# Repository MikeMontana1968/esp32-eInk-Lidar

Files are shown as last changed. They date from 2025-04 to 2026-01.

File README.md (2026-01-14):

# ESP32 eInk+LiDAR Motorcycle Fuel Gauge

An ESP32-based fuel tank monitoring system using a LIDAR sensor and e-ink display. Designed for vehicle fuel level monitoring with real-time display of fuel percentage, remaining gallons, estimated range, and historical consumption data.

The lidar (a vlx sensor from ada-fruit) sensor has a neobydium magnet epoxied to it so that it sticks to the upper-inside of the fuel tank and points down. The code reads the time-of-flight to the level of gasoline remaining in the tank about every 1s, with 10 reads spaced 10ms apart and weighted with std-dev to filter out vibrations, and sloshing effects of the surface. Orignially an ultra-sonic transducer was used but the gasoline destroyed the sensor. The overall accuracy is "good enough" to know when to get gas "soon". Some of my other repos explore other ways to estimate fuel consumption/range for the motorcycle.

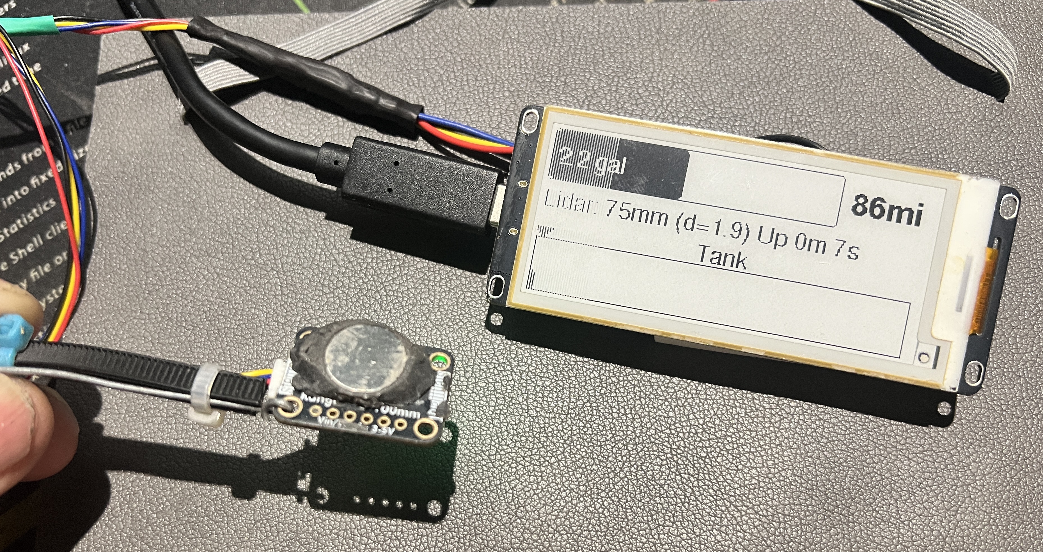
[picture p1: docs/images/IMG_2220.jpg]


Here's the 3d scan of the fuel tank. As you can see it's curved in three dimensions - the width curves out, then inward. As does the height along the horizontal axis. The curves are complex enough that a 5th order polynomial is needed to estimate fuel capacity for a given point on the z-axis. ClaudeAI was used to generate the polynomial <b>by working from the 3d scan of the tank</b> directly! Very impressive. The STL itself is available in .\stl\

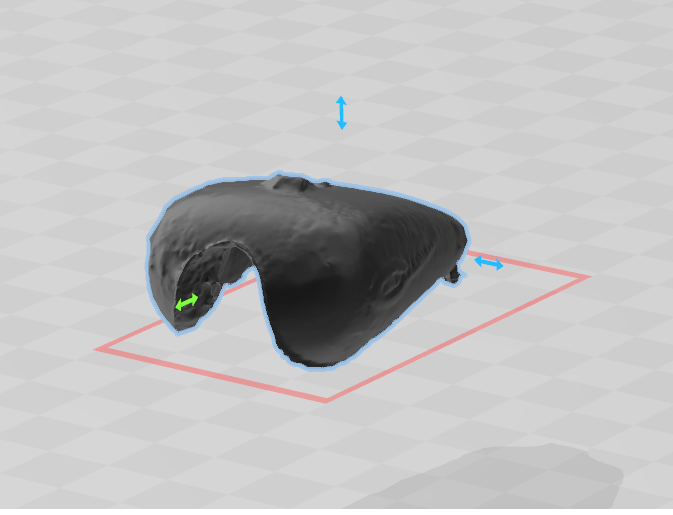
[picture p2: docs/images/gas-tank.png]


## Project Structure

```
heltec-gas-gauge/
├── platformio.ini              # PlatformIO build configuration
├── src/
│   ├── main.cpp                # Main entry point
│   ├── classes/
│   │   ├── EinkDisplayTask.cpp     # E-ink display task
│   │   ├── MyTask.cpp          # FreeRTOS task base class
│   │   ├── TankCapacity.cpp    # Fuel volume calculations
│   │   └── VlxTask.cpp         # LIDAR sensor task (VL6180X)
│   └── README.md               # This file
└── stl/                        # 3D printable enclosure files
```

## Hardware Requirements

### Microcontroller
- **Heltec Vision Master E290** (ESP32-S3 based board with integrated e-ink display)
- 296x128 pixel e-ink display

### Sensor
- **Adafruit VL6180X** Time-of-Flight LIDAR sensor
- Range: 0-255mm
- Mounted above fuel tank to measure fuel level depth

### Pin Configuration
| Function | GPIO Pin |
|---|---|
| I2C SDA  | GPIO 39  |
| I2C SCL  | GPIO 38  |
| VEXT Power | GPIO 18 |

### Tank Configuration Defaults
| Parameter | Default Value |
|---|---|
| Full tank distance | 10mm |
| Empty tank distance | 152mm |
| Tank capacity | 4.5 gallons |
| Average MPG | 40 |
| Screen refresh interval | 10 seconds |

## Build Process (PlatformIO)

### Prerequisites
- [VS Code](https://code.visualstudio.com/) with [PlatformIO extension](https://platformio.org/install/ide?install=vscode)

### platformio.ini
```ini
[env:vision-master-e290]
platform = espressif32
board = heltec_wifi_lora_32_V3
framework = arduino
monitor_speed = 115200
monitor_filters = esp32_exception_decoder
board_upload.use_1200bps_touch = true
build_flags =
  -D ARDUINO_USB_CDC_ON_BOOT=1
  -D Vision_Master_E290
  -D CORE_DEBUG_LEVEL=4
```

### Log Levels (CORE_DEBUG_LEVEL)
| Value | Level | Shows |
|---|---|---|
| 0 | None | Nothing |
| 1 | Error | `ESP_LOGE` only |
| 2 | Warn | `ESP_LOGE`, `ESP_LOGW` |
| 3 | Info | `ESP_LOGE`, `ESP_LOGW`, `ESP_LOGI` |
| 4 | Debug | All above + `ESP_LOGD` |
| 5 | Verbose | Everything including `ESP_LOGV` |

### Build and Upload
```powershell
pio run --target upload
```

### Monitor Serial Output
```powershell
pio device monitor
```

## Architecture

The system uses FreeRTOS to run two independent tasks:

| Task | Stack Size | Priority | Function |
|---|---|---|---|
| VlxTask | 8192 bytes | 3 | Continuously samples LIDAR sensor (~20 samples/cycle) |
| EinkDisplayTask | 16384 bytes | 3 | Updates e-ink display periodically |

### Source Files

| File | Description |
|---|---|
| `main.cpp` | Main entry point, initializes tasks |
| `classes/VlxTask.cpp` | LIDAR sensor driver, calculates mean/stddev, maintains history buffer |
| `classes/EinkDisplayTask.cpp` | Renders fuel gauge, stats, and historical graph on e-ink |
| `classes/TankCapacity.cpp` | Converts distance readings to volume using tank geometry |
| `classes/MyTask.cpp` | FreeRTOS task wrapper base class |

### Data Flow
1. VlxTask reads 20 samples from VL6180X sensor per cycle
2. Calculates average distance and standard deviation
3. Stores result in 200-element ring buffer for history
4. EinkDisplayTask retrieves latest data via mutex-protected access
5. TankCapacity converts distance to volume (gallons/liters)
6. Display renders fuel gauge, statistics, and historical bar graph

## Display Features

- Current fuel level percentage with bar graph
- Remaining fuel volume (gallons)
- Estimated driving range (miles)
- 200-sample historical fuel level graph
- Sensor uptime and status
- Error messages for sensor failures

## Customization

Tank parameters can be set when creating the EinkDisplayTask:

```cpp
einkTask = new EinkDisplayTask(
    I2C_SDA, I2C_SCL,   // I2C pins
    vlxTask,            // Pointer to VlxTask
    10,                 // mmFullTank - distance when full
    152,                // mmEmptyTank - distance when empty
    4.5,                // galCapacity - tank capacity in gallons
    40,                 // mpgAvg - average fuel economy
    10                  // secRefresh - display refresh interval
);
```

## 3D Printed Enclosure

STL files for a custom enclosure are included in the `/stl/` directory:
- `E290 Bottom.stl` - Bottom housing
- `E290 Top.stl` - Top housing
- `E290 Buttons.stl` - Button interface

## Dependencies

Managed automatically by PlatformIO:
- `heltec-eink-modules` - Heltec e-ink display driver
- `Adafruit_VL6180X` - VL6180X LIDAR sensor driver
- `Adafruit_GFX` - Graphics library

## License

See LICENSE file for details.

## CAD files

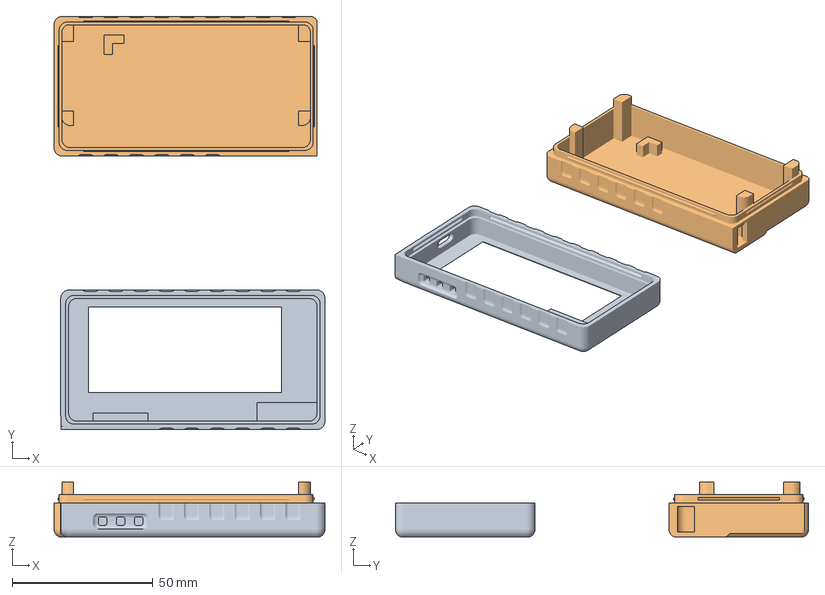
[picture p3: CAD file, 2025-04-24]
stl/E290 Top2.3mf
96.2 x 146.7 x 19.5 mm

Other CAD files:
stl/3dscan-of-fuel-tank.stl
stl/E290 Bottom.stl
stl/E290 Top.stl
stl/E290 Buttons.stl

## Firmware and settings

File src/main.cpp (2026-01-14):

/*
Set Board Type to: Vision Master E290
https://github.com/todd-herbert/heltec-eink-modules/blob/main/docs/WirelessPaper/wireless_paper.md

*/
#define LOG_LOCAL_LEVEL ESP_LOG_VERBOSE
#define I2C_SDA GPIO_NUM_39
#define I2C_SCL GPIO_NUM_38
#define TAG_MAIN "main"

#include "classes/VlxTask.cpp"
#include "classes/EinkDisplayTask.cpp"

VlxTask *vlxTask;
EinkDisplayTask *einkTask;

void setup() {
    ESP_LOGE(TAG_MAIN, "Setup!");
	Serial.begin(115200);
    Serial.print("Running Version: ");
    Serial.println(TAG_MAIN);
    
    vlxTask = new VlxTask(I2C_SDA, I2C_SCL);
    einkTask = new EinkDisplayTask(I2C_SDA, I2C_SCL, vlxTask);

    vlxTask->start();
    einkTask->start();
    ESP_LOGE(TAG_MAIN,"Setup Complete");
}

void loop() {
    ESP_LOGV(TAG_MAIN, ".");
    vTaskDelay(10000 / portTICK_PERIOD_MS);
}

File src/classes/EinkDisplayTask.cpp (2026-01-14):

#pragma once
#include <heltec-eink-modules.h>
#include "Fonts/FreeSans9pt7b.h"
#include "Fonts/FreeSansBold9pt7b.h"
#include "Fonts/FreeSansBold12pt7b.h"
#include "Fonts/FreeMono9pt7b.h"

#include "freertos/FreeRTOS.h"
#include "freertos/task.h"
#include "esp_log.h"
#include "string.h"
#include "MyTask.cpp"
#include "VlxTask.cpp"
#include <Wire.h>
#include <driver/adc.h>

#include <Adafruit_GFX.h>    // Core graphics library
#include "TankCapacity.cpp"

#define TAG_EINK "eink"
#define E290_WIDTH  290
#define E290_HEIGHT 128

class EinkDisplayTask : public MyTask {
    /*
        https://github.com/todd-herbert/heltec-eink-modules/blob/main/docs/VisionMaster/vision_master.md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
    */
    private:
    int     percentFull = 0;   // updateDisplay()
    float   galRemain = 0;   // updateDisplay
    char    buf[256] = {0};
    uint16_t text_width = 0;
    uint16_t text_height = 0;
    uint16_t radius = 3;
    uint16_t bargraph_height = 40;
    uint16_t bargraph_width = 225;
    uint16_t offset = 1;
    String b = "";
    VlxTask* vlxTask;
    
    EInkDisplay_VisionMasterE290 display;

    const int   mmFullTank;
    const int   mmEmptyTank;
    const float galCapacity;
    const int   mpgAvg;
    const int   secRefresh;
    char sFuelRemain[80] = {0};
    char sRangeEst[10] = {0};
    char sLidarUptime[80] = {0};
    vlx_state data;
public:
    EinkDisplayTask(                
                gpio_num_t i2c_sda_pin,
                gpio_num_t i2c_slc_pin, 
                VlxTask* _VlxTask, 
                uint _mmFullTank = 10, 
                uint _mmEmptyTank = 152, 
                float _galCapacity = 4.5, 
                int _mpgAvg = 40, 
                int _secRefresh = 10
            ) : 
            MyTask(TAG_EINK, 16384, 3), 
            vlxTask(_VlxTask), 
            mmFullTank(_mmFullTank),
            mmEmptyTank(_mmEmptyTank),
            mpgAvg(_mpgAvg),
            galCapacity(_galCapacity),
            secRefresh(_secRefresh) 
        {
        // Wire already initialized by VlxTask
        ESP_LOGI(TAG_EINK, "Full %dmm Empty %dmm", _mmFullTank, _mmEmptyTank);
        ESP_LOGI(TAG_EINK,"Constructor Complete");
    }

    // Formats uptime as human-readable string (e.g., "5h 23m" or "2d 3h")
    void getUptime(char *result) {
        unsigned long seconds = millis() / 1000UL;
        int days = seconds / 86400; // 86400 seconds in a day
        seconds %= 86400;
        int hours = seconds / 3600; // 3600 seconds in an hour
        seconds %= 3600;
        int minutes = seconds / 60;
        seconds %= 60;

        if (days >= 1) {
            sprintf(result, "%dd %d%h", days, hours);
        } else if (hours >= 1) {
            sprintf(result, "%dh %dm", hours, minutes);
        } else {
            sprintf(result, "%dm %ds", minutes, seconds);
        }
    }

    // Fetches latest sensor data from VlxTask
    void read_lidar_values() {
       vlxTask->getUpdate(&data);
        if(data.avg_lidar_mm < 0) {
            ESP_LOGE(TAG_EINK, "No valid LIDAR readings. Check wiring and I2C address.");
        } else {
            ESP_LOGI(TAG_EINK, "LIDAR: %dmm", int(data.avg_lidar_mm));
        }
    }

    // Main display update - calculates fuel level and redraws e-ink screen
    void updateDisplay() {
        char szTemp[32] = {0};
        read_lidar_values();
        if(data.avg_lidar_mm < 0) {
            noI2CReadings();
            return;
        }

        TankCapacity tankCapacity(mmFullTank - mmEmptyTank, galCapacity * 3.78541f); // Convert gal to liters for TankCapacity        
        float height_of_fuel_mm = data.avg_lidar_mm - mmEmptyTank; // Adjust the raw LIDAR reading to be relative to the empty tank level 
        percentFull = tankCapacity.getFillPercent(height_of_fuel_mm); //float from 0 to 100

        memset(sFuelRemain, 0, sizeof(sFuelRemain));
        galRemain = tankCapacity.getVolumeGallons(height_of_fuel_mm);
        
        b = String(galRemain, 1) + " gal";
        if(galRemain < 1) {
            b = " GET GAS!";
        }
        b.toCharArray(sFuelRemain, b.length() + 1);
        
        memset(sRangeEst, 0, sizeof(sRangeEst));
        b = String(int(mpgAvg * galRemain)) + "mi";
        b.toCharArray(sRangeEst, b.length() + 1);

        memset(szTemp, 0, sizeof(szTemp));
        getUptime(szTemp);

        if(strlen(data.error_message)) {
            b = String(data.error_message) + " " + szTemp;
        } else {
            b  =  "Lidar: " + String(data.avg_lidar_mm, 0) + String("mm (d=") + String(data.std_dev, 1) + ") Up " + szTemp;
        }
        
        memset(sLidarUptime, 0, sizeof(sLidarUptime));
        b.toCharArray(sLidarUptime, b.length() + 1);

        ESP_LOGI(TAG_EINK, "%s, %s, %s", sFuelRemain, sRangeEst, sLidarUptime);
        // https://github.com/todd-herbert/heltec-eink-modules/blob/main/docs/README.md#drawline
        // https://learn.adafruit.com/adafruit-gfx-graphics-library/graphics-primitives
        display.clearMemory();  // Start a new drawing
        display.landscape();
        display.setTextColor(BLACK);
        display.setFont( &FreeSans9pt7b );
            drawTankFull();
            drawTankHistory();
        display.update();
    }

    // Draws the fuel level bar graph and range estimate
    void drawTankFull() {
        // ------------------------ Percent Full Bar graph -----------------------------
    
        display.setFont( &FreeSans9pt7b );
        display.drawRect(0,0, bargraph_width, bargraph_height, WHITE);
        display.drawRoundRect(0,0, bargraph_width, bargraph_height, radius, BLACK);

        uint16_t w = map(percentFull, 0, 100, offset, bargraph_width - offset);
        uint16_t bx, by, bh, bw = 0;
        text_width = display.getTextWidth(sFuelRemain);
        text_height = display.getTextHeight(sFuelRemain);
        bx = offset;
        by = offset;
        bh = bargraph_height - offset-offset;
        bw = w;

        display.fillRoundRect(bx, by, bw, bh, radius, BLACK);
        if(bw > text_width) {
            // the pct-full graph would fit the text, so left align the text in white
            display.setCursor(bx + 4, by + text_height * 1.5);
            display.setTextColor(WHITE);
        } else {
            // the pct-full graph is really low, so the text is too wide. Position the cursor just after the graph and print in Black
            display.setCursor(bw + offset, by + text_height * 2);
            display.setTextColor(BLACK);
        }
        display.print(sFuelRemain); // eg "4.5 gal" or "GET GAS!"

        // ---- Print the range to the right of the PctFull graph --------
        display.setFont( &FreeSansBold12pt7b );

        text_width = display.getTextWidth(sRangeEst);
        text_height = display.getTextHeight(sRangeEst);
        display.setTextColor(BLACK);
        display.setCursor(E290_WIDTH - text_width - 6, text_height *1.5);
        display.print(sRangeEst); // eg "127 mi"
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

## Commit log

2025-04-23 Fuel Gauge for 2012 Victory Highball using Heltec Vision Master E290 and Adafruit TimeOfFlight LIDAR
    [E290 Bottom.stl, E290 Buttons.stl, E290 Top.stl]
2025-04-24 Ready for test on Victory motorcycle
2025-04-24 Fix: Now timeout and continue if can not connect to wifi
    [E290 Top2.3mf]
2025-04-29 Phase 1 of proper UI
    Changed behavior of sample_vlx to simply record 0 as a measurement rather than cont try to get a value.
    Added bar-graph etc to main display
2025-05-02 Added Startup screen to show config
    Startup screen helps to recognize when the device is powered up vs "stuck" on a reading.
    [heltec-gas-gauge.ino]
2025-05-15 Refactor to use RTOS tasks
    Significant update. Moved the vlx-sampler to its own task, and the eink updater to another task.
    There is still a todo to encapsulate the lidar value, and array of values into a mutex-controlled class.
    The eInk display will now show an error msg if the i2c-vlx fails to init.
    [eink_display.h, heltec-gas-gauge.ino]
2025-05-19 Added i2c pin #s to constructors
2026-01-14 Migrate from Arduino IDE to PlatformIO structure
    Move source files to src/ directory and add platformio.ini configuration
    for Heltec WiFi LoRa 32 V3 board with ESP32 debugging support.
2026-01-14 Fix stack overflow crashes and improve task stability
    - Increase eink task stack from 2048 to 16384 bytes
    - Increase vlx task stack from 4096 to 8192 bytes
    - Fix mutex pattern: use class member instead of creating/deleting per call
    - Replace float printf formatting with integer math to reduce stack usage
    - Add TankCapacity module for fuel level calculations
    - Add debug logging to trace task execution
    - Fix memset argument order in several places
    [eink_display.cpp, vlx_sampler.cpp]
2026-01-14 Rename source files and add function comments
    - Rename eink_display.cpp -> EinkDisplay.cpp
    - Rename vlx_sampler.cpp -> VLXTask.cpp
    - Rename heltec-gas-gauge.ino -> main.cpp
    - Add summary comments to all functions
    - Update README with project structure and current settings
2026-01-14 Add Git LFS tracking for STL files and add fuel tank 3D scan
    - Configure LFS to track *.stl files
    - Migrate existing STL files to LFS
    - Add 3dscan-of-fuel-tank.stl
    [3dscan-of-fuel-tank.stl, E290 Bottom.stl, E290 Buttons.stl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]
2026-01-14 Add LiDAR sensor implementation details to README
    Describes VLX sensor mounting, sampling strategy with std-dev filtering,
    and notes on why ultrasonic was replaced.
